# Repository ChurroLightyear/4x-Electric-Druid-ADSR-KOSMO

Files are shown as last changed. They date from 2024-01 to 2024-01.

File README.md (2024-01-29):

# 4x-Electric-Druid-ADSR-KOSMO (UN TESTED)
A kind of crude envelope generator based around the ENVGEN 8C chip from electric druid and LMNC's circuit for the mini ADSR

I originally designed this on stripboard which It's worked great since but after moving my modules around and debugging over 50+ wires for which one may have shorted I decided to make a PCB layout. The old stripboard layout works fine but It's ALOT of wired connections and 2 boards.
This is a PCB layout for a 4 envelope generators based around LMNC's ADSR and the electric druid chip ENV GEN 8C.
This has the a level knob added and it's 6 knobs ADSR time and level with a mode switch (ADSR, Gated loop and loop) and 16 jacks (a gate input, 2 output and a negative output for each envelope)
Theres a panel layout with the holes for everything except the LED's which I added after. I'm still using my old painted aluminum panel for this but The space for optional LEDs are on the Main PCB.
There's also holes on the panel that fit the Tayda stripboard mounting holes.
The LEDs are connected directly to the output so there may be some voltage drop but I've not noticed anything on the stripboard version
This module is untested the stripboard layout works

The files for the PCBs are all layed out in Kicad

UPDATE circuit has been verified and tested but there is a single missing trace for envelope 3
Between R27 and R49 be sure to a trace or jumper between those Reuploading the fixed board

The files on github have been updated with the missing trace, Everything should work as expected.
Added a BOM for both boards***



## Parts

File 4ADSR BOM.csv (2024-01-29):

Reference(s) | Value | Vendor
C1, C2, C3, C4, C5, C6, C7, C13, C14, C15, C16, C17, C18 | 100n Ceramic | Tayda
C8, C9, c10 | 10uf Elec | Tayda
C11, C12 | 10n Film | Tayda
C19 | 100n Film | Tayda
D1, D4, D5, D6 | 1N4148 | Tayda
D2, D3 | 1N5817 | Tayda
POWER | 10 Pin Box Header | Tayda
BOARD CONNECT | 10 Pin Box Header | Tayda
LED’s 1-4 | 5mm LED | Tayda
Jacks 1-16 | Neutrik Stereo Jacks | Tayda
Q1, Q2, Q3, Q4 | 2N3904 | Tayda
R1, R2, R9, R10, R16, R17, R23, R24, R25, R26 | 10k | Tayda
R3, R4, R5, R6, R7, R8 | 1k | Tayda
R11, R12, R14, R19, R20, R21, R29, R30, R31, R32, R33, R34 | 100k | Tayda
R13, R18, R27, R28 | 47k | Tayda
R15, R22, R35, R36 | 2K | Tayda
U1, U2, U3, U4 | ENV GEN 8C | Electric Druid
U5, U6 | TL074 | Tayda
U7 | LM7809 | Tayda
CONTROL BOARD
RV1, RV2, RV3, RV4, RV5, RV6 | B100k 9mm A-1848 | Tayda
R1, R2, 39, R4, R5, R6 | 1k | Tayda
R7, R8 | 10k | Tayda
C1, C2, C3, C4, C5, C6 | 100nf Ceramic | Tayda
SW1 | SPDT ON-OFF-ON | Tayda
J1 | 10 Pin Box Header | Tayda

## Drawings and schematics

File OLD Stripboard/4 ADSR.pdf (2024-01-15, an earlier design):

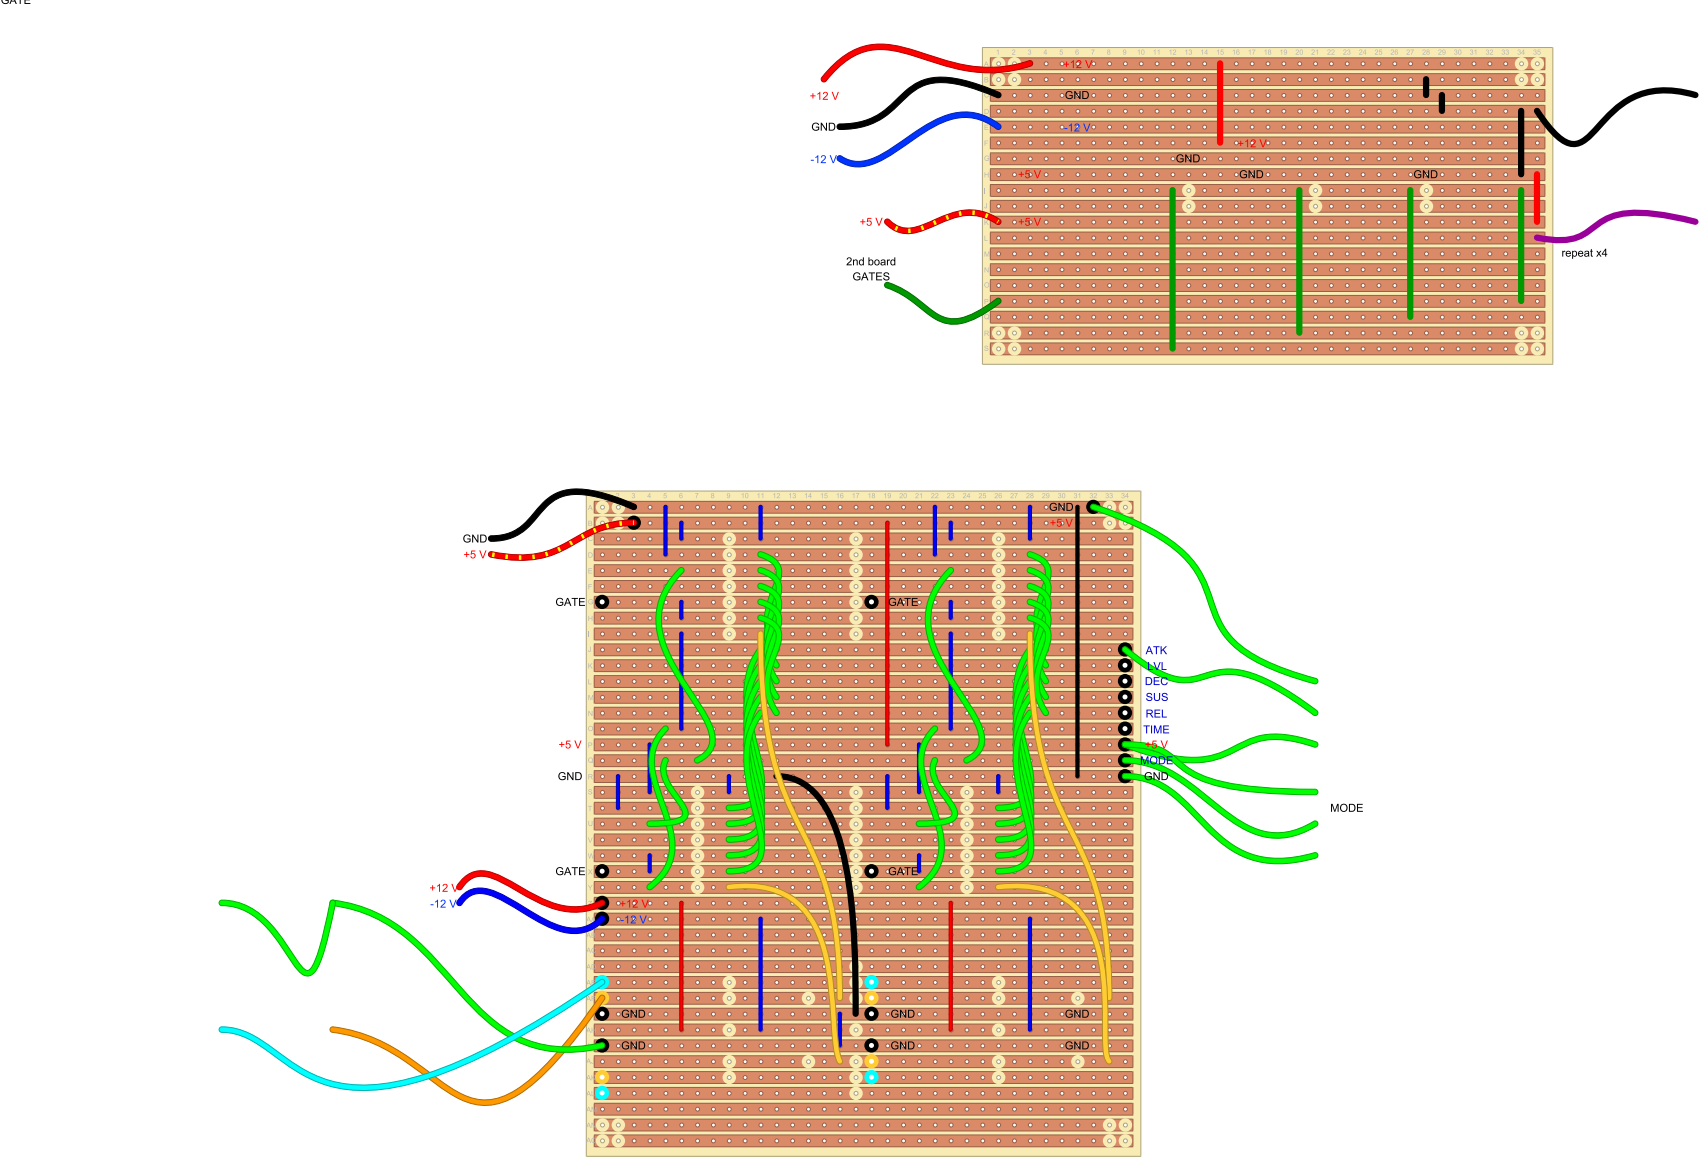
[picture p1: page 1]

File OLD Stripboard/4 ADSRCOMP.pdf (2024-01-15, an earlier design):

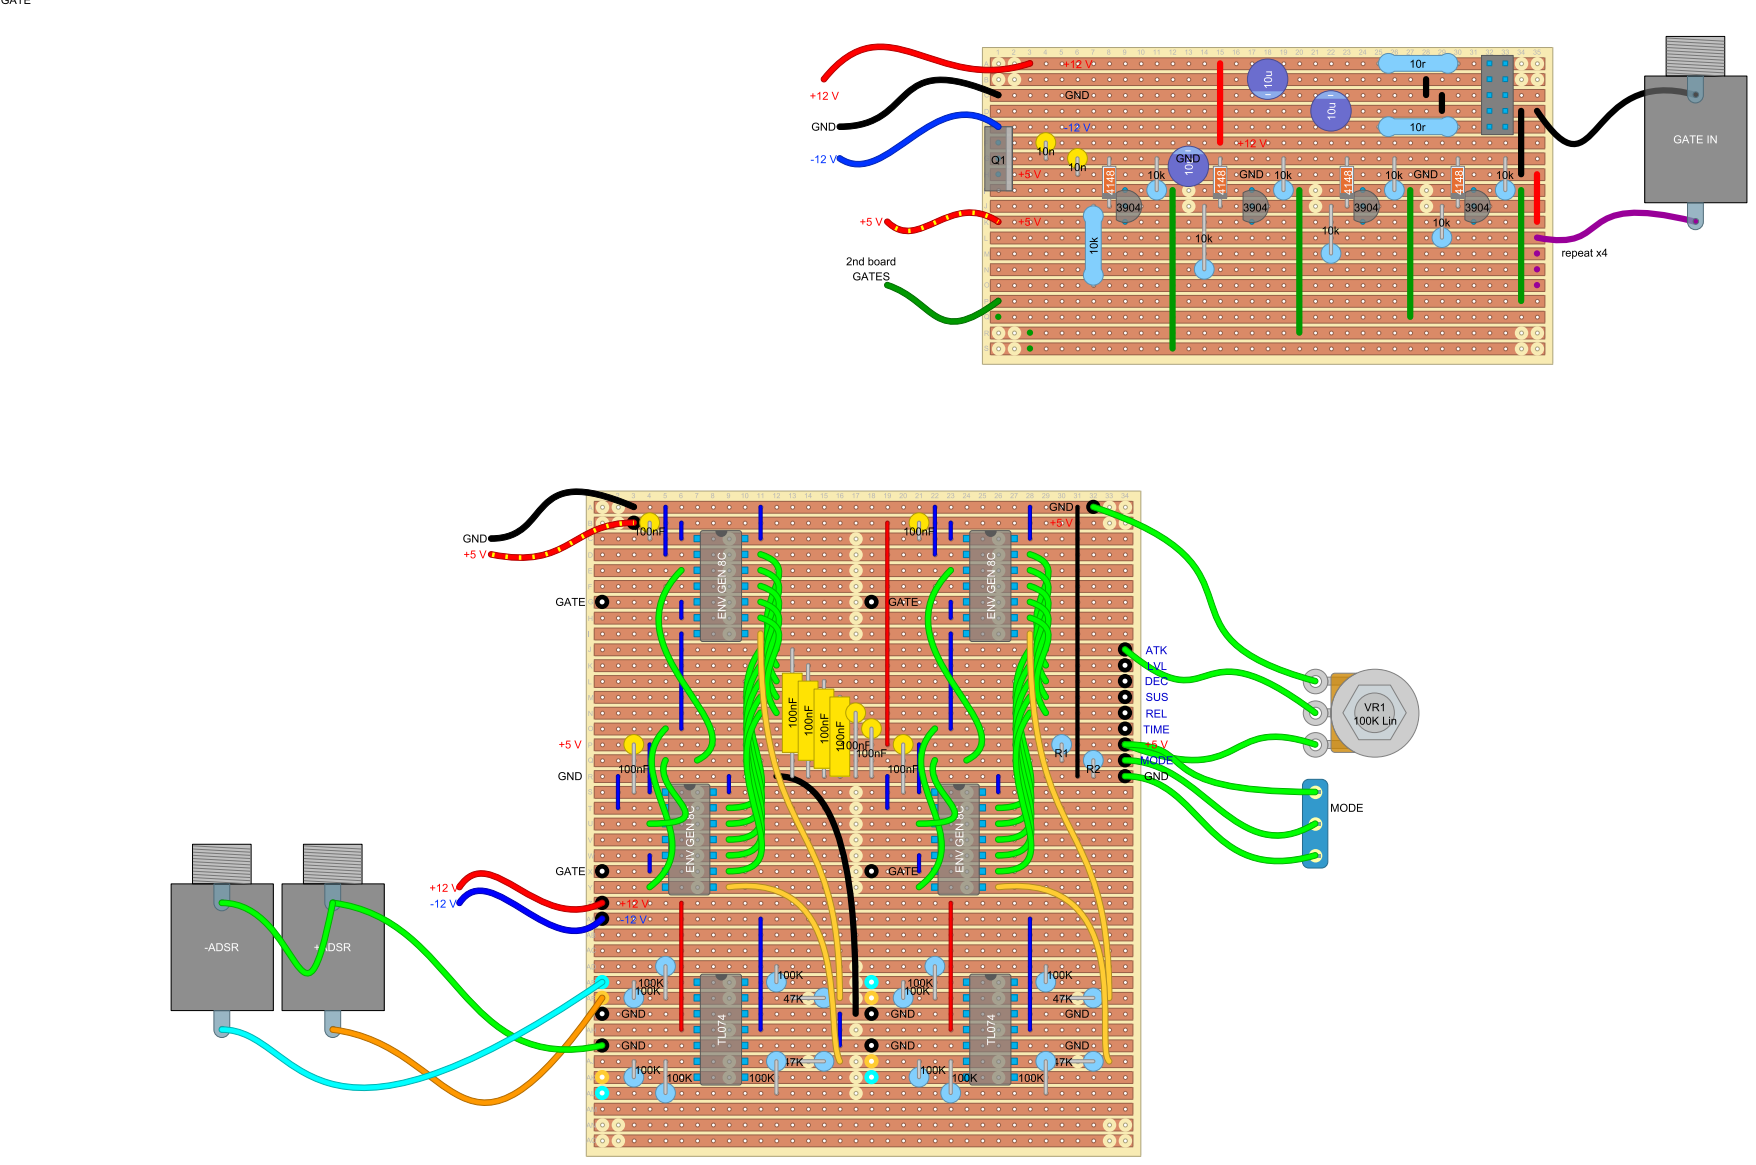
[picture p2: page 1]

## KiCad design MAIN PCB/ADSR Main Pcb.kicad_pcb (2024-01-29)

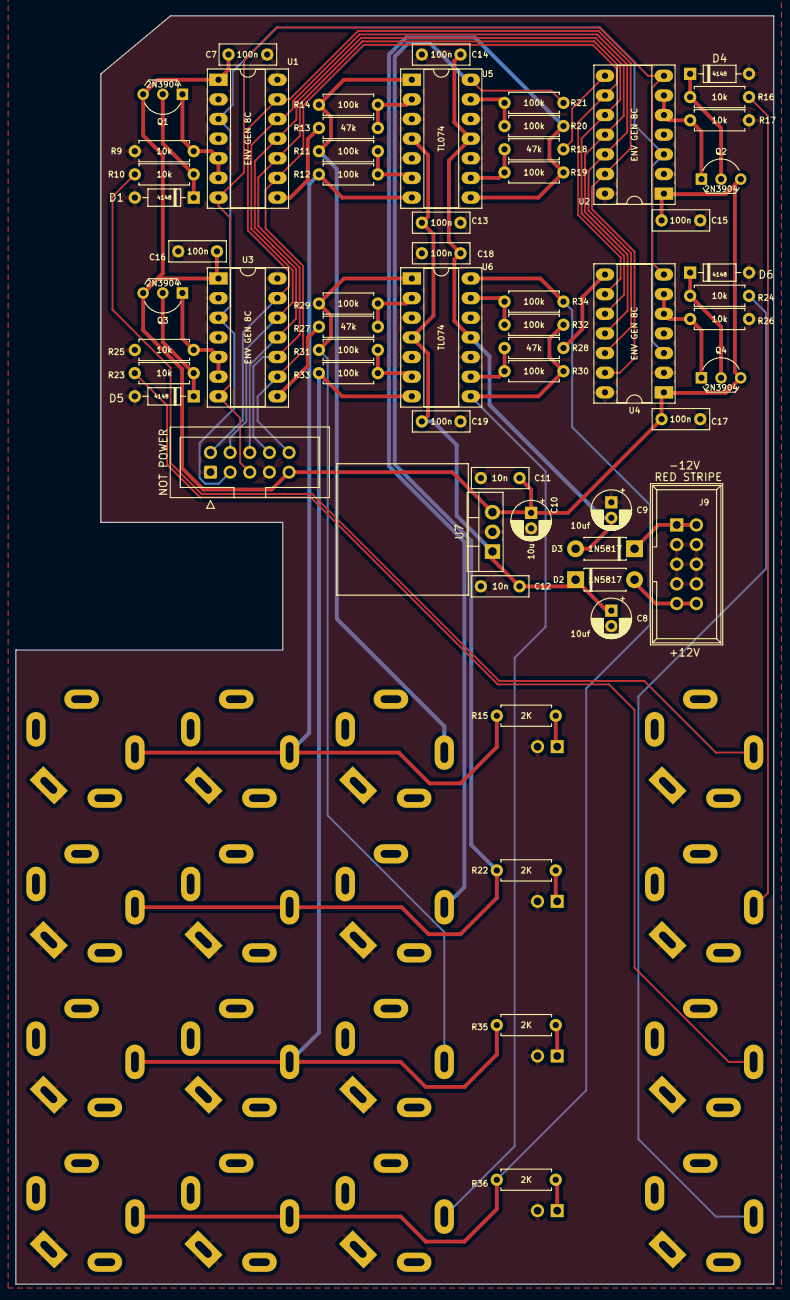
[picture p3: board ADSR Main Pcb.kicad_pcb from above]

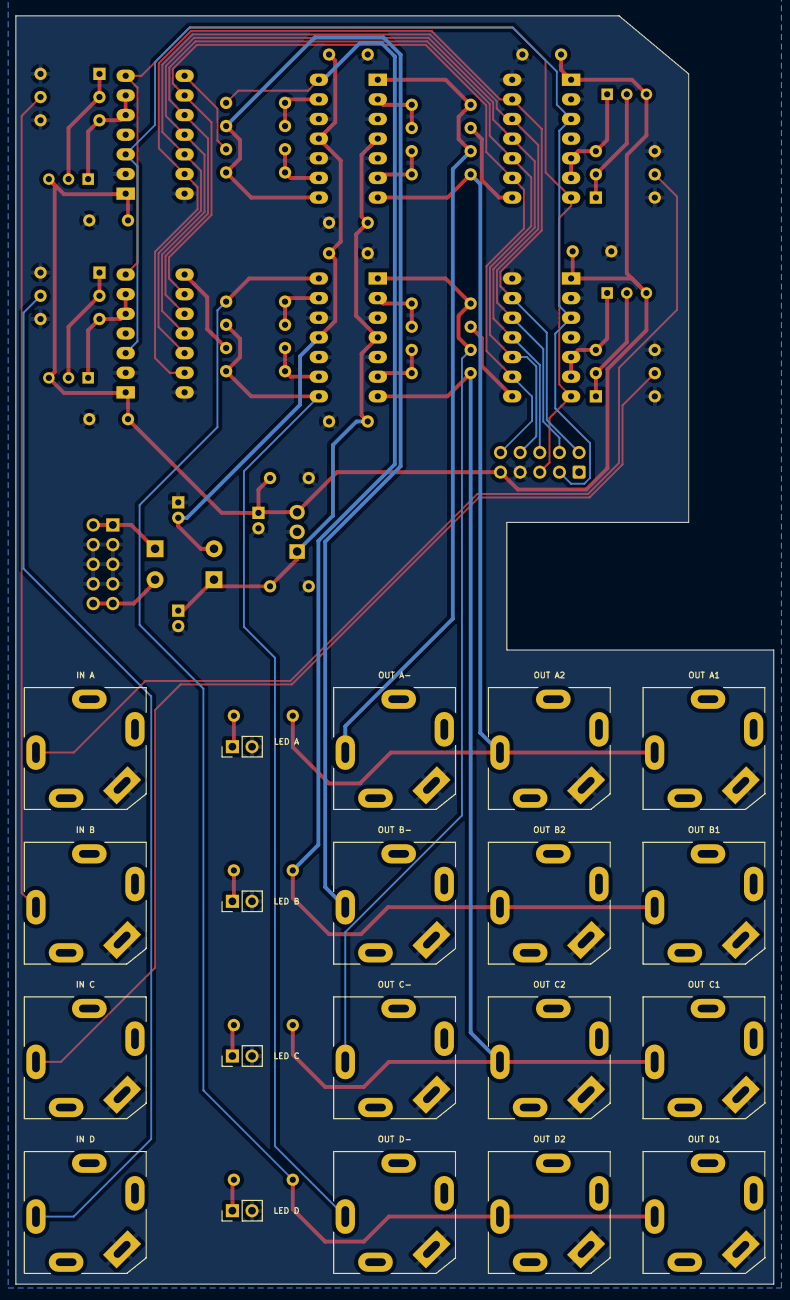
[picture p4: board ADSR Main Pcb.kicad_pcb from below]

Board: 2 copper layers, 98.0 x 164.0 mm, 80 parts (20 on the bottom side), 49 nets.

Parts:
C7, C13, C14, C15, C16, C17, C18, C19: 100n; C_Rect_L7.2mm_W2.5mm_P5.00mm_FKS2_FKP2_MKS2_MKP2
C8, C9: 10uf; CP_Radial_D5.0mm_P2.00mm
C10: 10u; CP_Radial_D5.0mm_P2.00mm
C11, C12: 10n; C_Rect_L7.2mm_W2.5mm_P5.00mm_FKS2_FKP2_MKS2_MKP2
D1, D4, D5, D6: 1N4148; D_DO-35_SOD27_P7.62mm_Horizontal
D2, D3: 1N5817; D_DO-41_SOD81_P7.62mm_Horizontal
IN A: Jack_6.35mm_PJ_629HAN_slots
IN B: Jack_6.35mm_PJ_629HAN_slots
IN C: Jack_6.35mm_PJ_629HAN_slots
IN D: Jack_6.35mm_PJ_629HAN_slots
J9: POWER; Power_Header
LED A: LED A; PinHeader_1x02_P2.54mm_Vertical
LED B: LED B; PinHeader_1x02_P2.54mm_Vertical
LED C: LED C; PinHeader_1x02_P2.54mm_Vertical
LED D: LED D; PinHeader_1x02_P2.54mm_Vertical
NOT POWER: IDC-Header_2x05_P2.54mm_Vertical
OUT A1, OUT A2: Jack_6.35mm_PJ_629HAN_slots
OUT A-: Jack_6.35mm_PJ_629HAN_slots
OUT B1, OUT B2: Jack_6.35mm_PJ_629HAN_slots
OUT B-: Jack_6.35mm_PJ_629HAN_slots
OUT C1, OUT C2: Jack_6.35mm_PJ_629HAN_slots
OUT C-: Jack_6.35mm_PJ_629HAN_slots
OUT D1, OUT D2: Jack_6.35mm_PJ_629HAN_slots
OUT D-: Jack_6.35mm_PJ_629HAN_slots
Q1, Q2, Q3, Q4: 2N3904; TO-92_Inline_Wide
R9, R10, R16, R17, R23, R24, R25, R26: 10k; R_Axial_DIN0207_L6.3mm_D2.5mm_P7.62mm_Horizontal
R11, R12, R14, R19, R20, R21, R29, R30, R31, R32, R33, R34: 100k; R_Axial_DIN0207_L6.3mm_D2.5mm_P7.62mm_Horizontal
R13, R18, R27, R28: 47k; R_Axial_DIN0207_L6.3mm_D2.5mm_P7.62mm_Horizontal
R15, R22, R35, R36: 2K; R_Axial_DIN0207_L6.3mm_D2.5mm_P7.62mm_Horizontal
U1, U2, U3, U4: ENV GEN 8C; DIP-14_W7.62mm_Socket_LongPads
U5, U6: TL074; DIP-14_W7.62mm_Socket_LongPads
U7: LM7809; TO-220-3_Vertical

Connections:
+5V: C7.2, C10.1, C11.1, C15.2, C16.2, C17.2, NOT POWER.9, Q1.3 (C), Q2.3 (C), Q3.3 (C), Q4.3 (C), U1.1 (5v), U2.1 (5v), U3.1 (5v), U4.1 (5v), U7.3 (VO)
+12V: C8.1, C12.2, C13.1, C19.1, D2.1 (K), U5.4 (V+), U6.4 (V+), U7.1 (VI)
-12V: C9.2, C14.2, C18.2, D3.2 (A), U5.11 (V-), U6.11 (V-)
ATK: NOT POWER.2, U1.13 (ATK), U2.13 (ATK), U3.13 (ATK), U4.13 (ATK)
DEC: NOT POWER.6, U1.11 (DEC), U2.11 (DEC), U3.11 (DEC), U4.11 (DEC)
ENV A: R13.1, U1.8 (OUT)
ENV B: R18.1, U2.8 (OUT)
ENV C: R27.1, U3.8 (OUT)
ENV D: R28.1, U4.8 (OUT)
GATE A: Q1.1 (E), R9.1, U1.5 (GATE), U1.6 (TRIG)
GATE B: Q2.1 (E), R17.1, U2.5 (GATE), U2.6 (TRIG)
GATE C: Q3.1 (E), R25.1, U3.5 (GATE), U3.6 (TRIG)
GATE D: Q4.1 (E), R26.1, U4.5 (GATE), U4.6 (TRIG)
GND: C7.1, C8.2, C9.1, C10.2, C11.2, C12.1, C13.2, C14.1, C15.1, C16.1, C17.1, C18.1, C19.2, D1.2 (A), D4.2 (A), D5.2 (A), D6.2 (A), IN A.S, IN B.S, IN C.S, IN D.S, J9.3 (GND), J9.4 (GND), J9.5 (GND), J9.6 (GND), J9.7 (GND), J9.8 (GND), LED A.2, LED B.2, LED C.2, LED D.2, NOT POWER.1, NOT POWER.7, OUT A1.S, OUT A2.S, OUT A-.S, OUT B1.S, OUT B2.S, OUT B-.S, OUT C1.S, OUT C2.S, OUT C-.S, OUT D1.S, OUT D2.S, OUT D-.S, R9.2, R17.2, R25.2, R26.2, U1.2 (Punch), U1.14 (GND), U2.2 (Punch), U2.14 (GND), U3.2 (Punch), U3.14 (GND), U4.2 (Punch), U4.14 (GND), U5.3 (+), U5.5 (+), U5.10 (+), U5.12 (+), U6.3 (+), U6.5 (+), U6.10 (+), U6.12 (+), U7.2 (GND)
LVL: NOT POWER.4, U1.12 (LVL), U2.12 (LVL), U3.12 (LVL), U4.12 (LVL)
MODE: NOT POWER.3, U1.3 (MODE), U2.3 (MODE), U3.3 (MODE), U4.3 (MODE)
unnamed: D1.1 (K), Q1.2 (B), R10.2
unnamed: D2.2 (A), J9.9 (+12V), J9.10 (+12V)
unnamed: D3.1 (K), J9.1 (-12V), J9.2 (-12V)
unnamed: D4.1 (K), Q2.2 (B), R16.2
unnamed: D5.1 (K), Q3.2 (B), R23.2
unnamed: D6.1 (K), Q4.2 (B), R24.2
unnamed: IN A.T, R10.1
unnamed: OUT A1.T, OUT A2.T, R12.2, R15.1, U5.7
unnamed: OUT A-.T, R11.1, R14.2, U5.1
unnamed: LED A.1, R15.2
unnamed: IN B.T, R16.1
unnamed: LED B.1, R22.2
unnamed: OUT B1.T, OUT B2.T, R21.2, R22.1, U5.14
unnamed: OUT B-.T, R19.2, R20.1, U5.8
unnamed: IN C.T, R23.1
unnamed: IN D.T, R24.1
unnamed: LED C.1, R35.2
unnamed: OUT C1.T, OUT C2.T, R33.2, R35.1, U6.7
unnamed: OUT C-.T, R29.2, R31.1, U6.1
unnamed: LED D.1, R36.2
unnamed: OUT D1.T, OUT D2.T, R34.2, R36.1, U6.14
unnamed: OUT D-.T, R30.2, R32.1, U6.8
unnamed: R13.2, R14.1, U5.2 (-)
unnamed: R11.2, R12.1, U5.6 (-)
unnamed: R18.2, R19.1, U5.9 (-)
unnamed: R20.2, R21.1, U5.13 (-)
unnamed: R27.2, R29.1, U6.2 (-)
unnamed: R31.2, R33.1, U6.6 (-)
unnamed: R28.2, R30.1, U6.9 (-)
unnamed: R32.2, R34.1, U6.13 (-)
REL: NOT POWER.10, U1.9 (REL), U2.9 (REL), U3.9 (REL), U4.9 (REL)
SUS: NOT POWER.8, U1.10 (SUS), U2.10 (SUS), U3.10 (SUS), U4.10 (SUS)
TIME: NOT POWER.5, U1.7 (TIME), U2.7 (TIME), U3.7 (TIME), U4.7 (TIME)
